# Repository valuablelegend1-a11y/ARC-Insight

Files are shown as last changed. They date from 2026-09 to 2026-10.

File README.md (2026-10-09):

# ARC-Insight 

## What it is:

ARC-Insight is a pair of AI glasses that directly connect to my homemade prompt transformer based AI: J.A.R.V.I.S. The frames carry the extensive payload of two bone conduction transducers for audio output, INMP441 and electret mics for audio input, a MAX30102 heart rate sensor for direct vitals tracking and emotion mapping, an OV2640 camera module for facial and object recognition, two 300mAh LiPo batteries for at least a full day of battery life at moderate usage, and to tie it all together; a custom ESP32-S3 based PCB!

The goal is a digital assistant that can come with me everywhere, while also expanding the abilities of Jarvis to do some things he couldn't from my desktop. He will be able to do things like answer personal questions, find search results, tell me what I'm holding or looking at, tell me who the person in front of me is, open up apps on my PC, start 3D prints, and even more. All while mapping my heartrate and speech patterns to respond with a genuine conversational feel through the GPT(NOT ChatGPT, they may have popularized the name GPT, but it just means a Generative Prompt Transformer, which is what Jarvis's speech is using).  

## How to use it:

First a quick primer, because this whole thing is two halves that have to work together, you have the glasses, which are the dumb half on purpose, they just record (microphone, camera, and your heart rate) and stream it all over Wi-Fi, and then you have Jarvis, which is the smart half, a desktop AI assistant I've been building for a while now, he's a custom language model with tools for things like object recognition, memory, web search, and much much more (I'm still deciding whether to ever make him open source, but if I do I'll drop a link here), and he does all the actual thinking and streams his reply back to the glasses so you hear it in your ears. Neither half is useful alone, you need both.

Setup happens in two places, and you only really do it once, the glasses and the PC.

The glasses half, the firmware lives in this repo at Code/firmware, you open it in PlatformIO (a coding tool for microcontrollers, sort of like a much more powerful Arduino IDE, it handles the build and the libraries for you), and before you build it the first time you need to put your Wi-Fi name and password, plus the address of the PC that runs Jarvis, into the little config file at Code/firmware/arcinsight_config.h (there are blanks right where they belong, you can't miss them), and then you plug the glasses in over USB, hit build and upload, and that's the only time you'll ever need a cable. After that the glasses just need power and to be on the same Wi-Fi as the PC, and they take care of themselves.

The PC half, you need Jarvis running (same desk assistant I mentioned, the glasses really are just a remote control for him), and you drop this arc_insight package into the same folder as the rest of his code, where it plugs in with a few lines and doesn't touch anything else (that was the whole design goal, he behaves exactly the same until the glasses show up), then you just start him up like normal, and when the glasses connect you'll see `ARCINSIGHT: glasses connected` in the console, and you're off.

Once they're connected it's all voice, you say "jarvis" (the same wake word you might already use at the desk, it becomes a habit fast) followed by whatever you need, like "what do you see", "who is this", "take a picture", or "how am I feeling", the last one is the heart rate sensor earning its keep, Jarvis reads your heartbeat, mixes it with the tone of what you said, and guesses if you're stressed or excited or just having a chill day, which is honestly the feature I'm most excited to see working. You can jump between the glasses and the desk whenever you want too, just say "jarvis, switch to glasses" or "jarvis, switch to laptop", or press Ctrl+Alt+G (the hotkey, it's easy to remap in the config), and Jarvis moves his ears, his mouth, and his eyes to wherever you are.

And when a newer firmware comes out, the cable stays in the drawer, you build the new image and run one little command, `python arc_insight\ota.py --bin ..\arc-insight\Code\.pio\build\arcinsight\firmware.bin`, and it streams the update over Wi-Fi on the same connection, the glasses verify it and reboot into the new version (if it fails the check they just stay on the old one, which is a nice safety net).

## Why I am building this:

- To learn real firmware development, power management, and how to package electronics into a wearable.
- To take Jarvis with me instead of keeping him chained to the desk.
- The heartbeat + speech sentiment combo lets Jarvis react to *how* I say things, not just *what* I say.

## Notes:

1. This is the first version of this project, so some things will change in future versions, like for instance the code may be optimized to run everything locally on the device, but that is not yet(look at note 3 for more information).
2. The code will not be all just written from memory for me for it all, I am still learning to code in general. That said, I really am diving deep into this, but it will still have some copy and paste from Google search, reddit snippets, or anything I need to make it work that I don't know.
3. Version 0 of this project is designed to be mostly a peripheral to my AI assistant J.A.R.V.I.S., who is a custom made Generative Prompt Transformer(GPT) based off of NanoGPT by Andrej Karpathy, with added tools for things like image and object recognition, memory, web search, and much much more. For more detail on that I will soon be making a repo to document that journey and how the AI runs now.
4. This is my first time designing a custom PCB, so forgive me if it is messy and not optimized, but I am quite proud of it and I think it will function how needed for this version.

## Assembly:


## Scehmatic:


## PCB:


## PCB Render:


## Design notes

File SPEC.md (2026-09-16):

# ARC-Insight Spec Sheet

## Architecture

The glasses are a 'wearable thin client'. The Jarvis brain stays on the desktop PC:

- Glasses (ESP32-S3 XIAO Sense): capture mic audio, on-demand camera frames, on-demand heart rate; play TTS audio via bone conduction.
- PC (Jarvis): STT (Google), the trained nanoGPT model, tools (weather, search, face rec via YOLO, memory, etc.), TTS (edge-tts). Streams synthesized audio back to the glasses.

The ESP32-S3 (512 KB SRAM) physically cannot run the Jarvis transformer, so no attempt is made to run a model on the frame.

## Hardware

- **Board:** Seeed Studio XIAO ESP32-S3 Sense (ESP32-S3R8, 240 MHz dual-core, 8 MB PSRAM, 8 MB flash)
- **Camera:** OV2640 / OV3660 on the Sense flex connector (2 MP), PSRAM-backed framebuffer
- **Mics:** onboard PDM mic (primary); external INMP441 I2S as fallback if placement is bad
- **Output:** 2x bone-conduction transducers behind the ears, driven by MAX98357A I2S amps
- **Sensors:** MAX30102 PPG heart-rate (I2C), power-gated
- **Power:** 2x ultra-slim 1S LiPo (300-400 mAh) in parallel -> XIAO BAT+ / BAT- pads, charged by onboard 100 mA charger via USB-C
- **Wake:** external electret + envelope comparator -> GPIO wake from deep sleep

## Power model

| State | Draw | Notes |
|---|---|---|
| Deep sleep (idle) | ~3 mA | Floor with Sense expansion attached; ~6-7 days on 2x300 mAh |
| Wake + streaming mic over Wi-Fi | ~55-110 mA | Mic-only ~54 mA, Wi-Fi active ~110 mA |
| Speaking (amp on) | +20-50 mA | Gate amp off otherwise |
| Camera capture | ~150-300 mA | Bursts only, <1 s per frame |
| Heart-rate burst | +1 mA | ~15-30 s samples on demand |
| Charge | 100 mA | Onboard charger, ~6 h to full |

Expected: ~1-2 days per charge with a couple hours of conversation per day.

## Emotion mapping (Jarvis tool)

Read heart rate in short bursts and combine with the sentiment of the latest utterance:

- High HR + negative words -> stressed
- High HR + positive/energetic words -> excited
- Low HR -> calm

Implemented later as a `read_mood` tool in the Jarvis `route_tool` pipeline.

3. On-device wake word (ESP-SR WakeNet) to stop constant streaming.
4. Camera capture -> JPEG -> PC YOLO (reuse existing vision tools).
5. Heart-rate sensor + DSP + logging.
6. Battery mgmt, carrier PCB, mechanical integration into the frame.

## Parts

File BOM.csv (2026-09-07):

Item | Quantity | Unit Price | Link | Notes
Custom PCB | 1 | 65.52 | no link | A custom designed PCB with an ESP32-S3 chip for processing.
OV2640 24-pin DVP camera module (75MM-120) | 1 | 8.19 | https://www.aliexpress.us/item/3256805763260734.html | 2MP, DVP 24-pin 0.5mm FPC.
Bone conduction transducer | 2 | 6.96 | https://www.aliexpress.us/item/3256808698640901.html | 8-16 ohm, electromagnetic GD-02 style compact drivers.
3.7V 300mAh Lipo Batterys | 2 | 3.99 | https://www.aliexpress.us/item/3256804324797087.html | Total of about 400mAh, should last a full day of use before charge.
GY-MAX30102 heart-rate breakout | 1 | 2.09 | https://www.aliexpress.us/item/3256810169517122.html | heart rate sensor for emotion mapping.
Electret mic | 1 | 2.36 | https://www.sameskydevices.com/product/audio/microphones/electret-condenser-microphones/cmc-4013-2-smt-tr | Always-on wake-on-sound, wakes ESP32 from deep sleep via GPIO. Only peripheral that stays powered in deep sleep.
5 pack INMP441 I2S mic (MH-ET LIVE) | 5 | 3.55 | https://www.aliexpress.us/item/3256809614473821.html | Primary speech mic I2S into S3.
Face Shield For Lenses | 1 | 6.99 | https://www.amazon.com/Saillong-Replacement-Compatible-Shields-Grinding/dp/B0D8L11X2C/ref=sr_1_5 | Transparent face shield to be cut to size for glasses lenses.
Signal Antenna | 1 | 7.02 | https://www.amazon.com/Adafruit-2-4GHz-Flexible-Antenna-Connector/dp/B01E43VXO0 | A 50Ω 100mm 4dBi Antenna, plugs into board's U.FL port.

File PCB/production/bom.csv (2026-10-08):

Comment | Designator | Footprint | Qty | LCSC Part #
ESP32-S3FN8R2 | U1 | QFN-56-1EP_7x7mm_P0.4mm_EP4x4mm | 1 | C2913196
MAX98357A | U2 | TQFN-16-1EP_3x3mm_P0.5mm_EP1.23x1.23mm | 1 | C910544
MAX98357A | U3 | TQFN-16-1EP_3x3mm_P0.5mm_EP1.23x1.23mm | 1 | C910544
TP4054 | U4 | SOT-23-5 | 1 | C382138
MCP6541 | U5 | SOT-23-5 | 1 | C80839
ME6211C33M5G-N | U6 | SOT-23-5 | 1 | C82942
USB_C_Receptacle | J1 | USB_C_Receptacle_GCT_USB4105-xx-A_16P_TopMnt_Horizontal | 1 | C3025063
FPC_24PIN | J6 | Hirose_FH12-24S-0.5SH_1x24-1MP_P0.50mm_Horizontal | 1 | C202112
U.FL-R-SMT-1(80) | J8 | U.FL_Hirose_U.FL-R-SMT-1_Vertical | 1 | C88374
40MHz | Y1 | Crystal_SMD_3215-2Pin_3.2x1.5mm | 1 | C47089401
2.4nH | L2 | L_0402_1005Metric | 1
12pF | C1 | C_0402_1005Metric | 1 | C1547
12pF | C2 | C_0402_1005Metric | 1 | C1547
100nF | C3 | C_0402_1005Metric | 1 | C1525
100nF | C4 | C_0402_1005Metric | 1 | C1525
100nF | C5 | C_0402_1005Metric | 1 | C1525
100nF | C6 | C_0402_1005Metric | 1 | C1525
1uF | C7 | C_0402_1005Metric | 1 | C52923
10uF | C8 | C_0603_1608Metric | 1 | C19702
10uF | C9 | C_0603_1608Metric | 1 | C19702
100nF | C10 | C_0402_1005Metric | 1 | C1525
1.5pF | C11 | C_0402_1005Metric | 1 | C1552
1.5pF | C12 | C_0402_1005Metric | 1 | C1552
1uF | C13 | C_0603_1608Metric | 1
10uF | C14 | C_0603_1608Metric | 1 | C19702
10k | R1 | R_0402_1005Metric | 1 | C25744
33R | R2 | R_0402_1005Metric | 1 | C25105
33R | R3 | R_0402_1005Metric | 1 | C25105
2.2k | R4 | R_0402_1005Metric | 1 | C25879
10k | R5 | R_0402_1005Metric | 1 | C25744
10k | R6 | R_0402_1005Metric | 1 | C25744
10k | R7 | R_0402_1005Metric | 1 | C25744
5.1k | R8 | R_0402_1005Metric | 1 | C105872
5.1k | R9 | R_0402_1005Metric | 1 | C105872

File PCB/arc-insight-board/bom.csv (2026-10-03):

Reference | Qty | Value | DNP | Exclude from BOM | Exclude from Board | Exclude from Simulation | Exclude from Position Files | Footprint | Datasheet
C1,C2 | 2 | 12pF |  |  |  |  | ${EXCLUDE_FROM_POS_FILES} | Capacitor_SMD:C_0402_1005Metric
C3,C4,C5,C6,C10 | 5 | 100nF |  |  |  |  | ${EXCLUDE_FROM_POS_FILES} | Capacitor_SMD:C_0402_1005Metric
C7 | 1 | 1µF |  |  |  |  | ${EXCLUDE_FROM_POS_FILES} | Capacitor_SMD:C_0402_1005Metric
C8,C9,C14 | 3 | 10µF |  |  |  |  | ${EXCLUDE_FROM_POS_FILES} | Capacitor_SMD:C_0603_1608Metric
C11,C12 | 2 | 1.5pF |  |  |  |  | ${EXCLUDE_FROM_POS_FILES} | Capacitor_SMD:C_0402_1005Metric
C13 | 1 | 1µF |  |  |  |  | ${EXCLUDE_FROM_POS_FILES} | Capacitor_SMD:C_0603_1608Metric
J1 | 1 | USB_C_Receptacle |  |  |  |  | ${EXCLUDE_FROM_POS_FILES} | Connector_USB:USB_C_Receptacle_GCT_USB4105-xx-A_16P_TopMnt_Horizontal | https://www.usb.org/sites/default/files/documents/usb_type-c.zip
J2 | 1 | Conn_01x06 |  |  |  |  | ${EXCLUDE_FROM_POS_FILES} | Resistor_SMD:R_Array_Convex_8x0602
J3 | 1 | Conn_01x05 |  |  |  |  | ${EXCLUDE_FROM_POS_FILES} | Resistor_SMD:R_Array_Convex_5x0603
J4,J5,J7 | 3 | Conn_01x02 |  |  |  |  | ${EXCLUDE_FROM_POS_FILES} | Connector_Wire:SolderWire-0.5sqmm_1x02_P4.6mm_D0.9mm_OD2.1mm
J6 | 1 | FPC_24PIN |  |  |  |  | ${EXCLUDE_FROM_POS_FILES} | Connector_FFC-FPC:Hirose_FH12-24S-0.5SH_1x24-1MP_P0.50mm_Horizontal
J8 | 1 | U.FL |  |  |  |  | ${EXCLUDE_FROM_POS_FILES} | Connector_Coaxial:U.FL_Hirose_U.FL-R-SMT-1_Vertical
L2 | 1 | 2.4nH |  |  |  |  | ${EXCLUDE_FROM_POS_FILES} | Inductor_SMD:L_0402_1005Metric
M1 | 1 | Electret |  |  |  |  | ${EXCLUDE_FROM_POS_FILES} | Sensor_Audio:CUI_CMC-4013-SMT
R1,R5,R6,R7 | 4 | 10kΩ |  |  |  |  | ${EXCLUDE_FROM_POS_FILES} | Resistor_SMD:R_0402_1005Metric
R2,R3 | 2 | 33Ω |  |  |  |  | ${EXCLUDE_FROM_POS_FILES} | Resistor_SMD:R_0402_1005Metric
R4 | 1 | 2.2kΩ |  |  |  |  | ${EXCLUDE_FROM_POS_FILES} | Resistor_SMD:R_0402_1005Metric
R8,R9 | 2 | 5.1k |  |  |  |  | ${EXCLUDE_FROM_POS_FILES} | Resistor_SMD:R_0402_1005Metric
U1 | 1 | ESP32-S3 |  |  |  |  | ${EXCLUDE_FROM_POS_FILES} | Package_DFN_QFN:QFN-56-1EP_7x7mm_P0.4mm_EP4x4mm | https://www.espressif.com/sites/default/files/documentation/esp32-s3_datasheet_en.pdf
U2,U3 | 2 | MAX98357A |  |  |  |  | ${EXCLUDE_FROM_POS_FILES} | Package_DFN_QFN:TQFN-16-1EP_3x3mm_P0.5mm_EP1.23x1.23mm | https://www.analog.com/media/en/technical-documentation/data-sheets/MAX98357A-MAX98357B.pdf
U4 | 1 | TP4054 |  |  |  |  | ${EXCLUDE_FROM_POS_FILES} | Package_TO_SOT_SMD:SOT-23-5
U5 | 1 | Comparator |  |  |  |  | ${EXCLUDE_FROM_POS_FILES} | Package_TO_SOT_SMD:SOT-23-5
U6 | 1 | ME6211C33M5 |  |  |  |  | ${EXCLUDE_FROM_POS_FILES} | Package_TO_SOT_SMD:SOT-23-5 | https://www.lcsc.com/datasheet/lcsc_datasheet_2304140030_MICRONE-Nanjing-Micro-One-Elec-ME6211C33R5G_C235316.pdf
Y1 | 1 | 40MHz |  |  |  |  | ${EXCLUDE_FROM_POS_FILES} | Crystal:Crystal_SMD_3215-2Pin_3.2x1.5mm

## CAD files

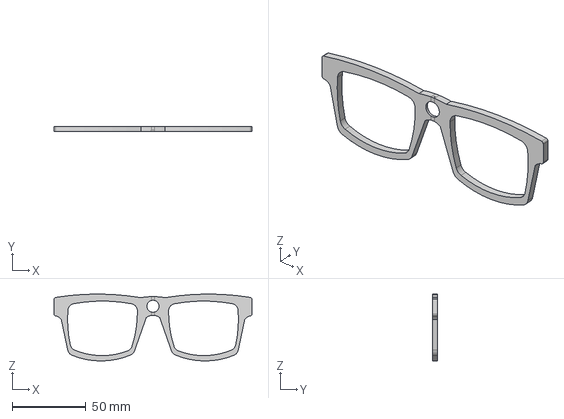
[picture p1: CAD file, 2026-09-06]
CAD/Step File Types/ARC-VisionFrames.step
134.6 x 3.69 x 45.5 mm

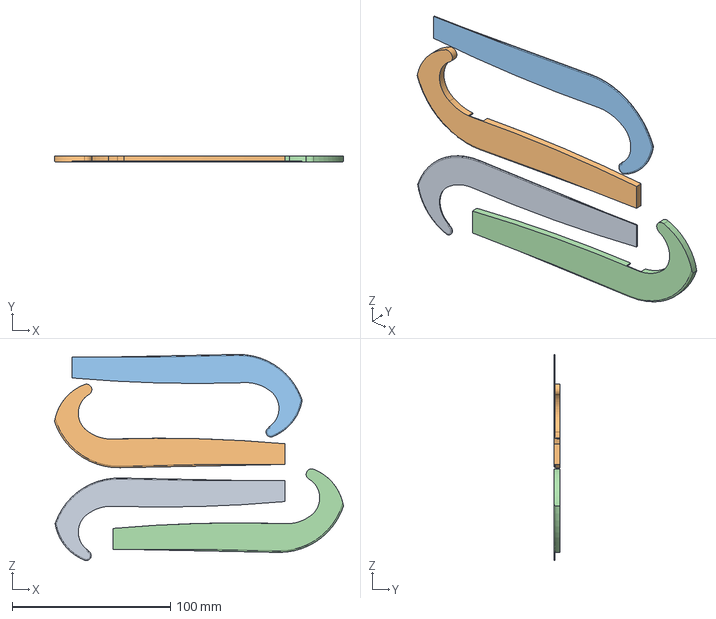
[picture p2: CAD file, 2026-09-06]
CAD/Step File Types/ARC-VisionArms.step
182.9 x 3.81 x 130.4 mm

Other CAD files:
CAD/Fusion File Types/ARC-VisionArms.f3z
CAD/Fusion File Types/ARC-VisionFrames.f3z

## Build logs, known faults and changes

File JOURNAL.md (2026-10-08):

---
Title: "ARC-Insight"
Author: "Jadon Persun"
Description: "AI glasses with a custom PCB"
Created At: 2026-08-07
---

# August 7: I made some basic drawings.
As usual for my projects I started off with some simple drawings of my idea, really the point of them is just to get a physical picture in my head before starting the true design process. Really the point of this whole build is to have a wearable device that I can use to communicate with my homebuilt, custom made transformer based AI: J.A.R.V.I.S. He also has tools and things to answer questions like weather, time, distances, facial recognition(through the camera), and more. For all of this, I decided to go with the Seeed Studio XIAO ESP32-S3 board, which is pretty small  and should work well. Then a couple other components that I know will be necessary, and I did a few renditions of the basic design to try to get a good style to fit what I was looking for, which I'm sure I will change more when I do the actual CAD of the project. For the most part these designs were simple, because the big benefit of small-scale projects is that there is literally just less area to manage. I also debated whether to go with some basic bluelight glasses lenses, or another simple option. Ultimately I decided that it would be slightly complex to try to model glasses frames around existing lenses, and really the point of these glasses is to be able to talk to J.A.R.V.I.S. when I'm AWAY from my computer, meaning bluelight would realistically not be needed.




**Time Spent: 1 Hour**

# August 10: I started designing.
So to start off the project I set up the repo, made a quick outline of how I want it to work, and made sure I knew what the requirements were. Then I started working on researching all the parts for the BOM, and I decided to use an ESP32-S3 mini version from seed studio for the main board(only 22mm tall) so I setup the rest of my components around that. I wanted the glasses to have good bone conduction transducers for audio, a heartbeat sensor for emotion analyzing, a camera for object and facial recognition, good mics for wake word detection and good input audio clarity, and plenty big batteries to make sure they would last the whole day. I also wanted the lenses to be a simple clear polycarbonate, as discussed in the previous entry, since trying to build the lenses frames around other lenses would be quite difficult. After getting a basic idea for each of the parts, I researched and made sure it would all work, then that it would all work together, and got it all nicely formatted in the BOM.csv file.




**Time Spent: 2 Hours**

# August 14: I started the CAD and pivoted my objective.
The next thing to work on was the CAD designs for the 3d printed frame(maybe later even made in metal by PCBWay!). The first thing I did before even starting my designs was to look up different glasses styles, I really wanted these to have the right look, and be stylish along with functional. It took me a couple tries of redoing the design completely, until I liked how the front frames came out. A pretty classic glasses look, but slightly redone to fit my face better and work correctly. Then there were the arms of the frame. These were much harder, because they needed to be big enough to fit all the components, and still look like glasses not a VR headset. Ultimately I realized that the board I had selected really would just not work for a low profile glasses frame. The size was too tall, the pins slightly too limited, and the usability did not fit my asparations. So I made a risky decision; I would design my first ever custom PCB. I got to work right away on researching how it all works, I have never done one before so there was a lot to learn. I decided on the ESP32-S3 chip still, because it had built in camera support and things like that that really fit what I needed. Before too long I had the basic framework of how to start, and I decided to start work on the schematic. This was a very time consuming process, since I didn't know anything about the software I was basically looking up every single baby step. Before too long I had figured out some keyboard shortcuts and had the basic idea down, then it came to the portion of the process where I just needed to carefully add all the parts correctly and get them all wired. After working on it almost every waking second of my day, I managed to finish the basic schematic with all the components I would need.




**Time Spent: 2.5 Hours**

# August 16: I continued work on the custom PCB.
So now that I got the schematic for the PCB all set up, it was time to start the actual component placement. At first I pretty much just threw everything in a rectangle in a way that they all fit together as tightly as possible with little bits of extra room. Then when I went to run the traces I realized I had not optimized it very well at all, out of my 200+ connections, *only 23 could be made.* So I went back to the drawing board, I tried rearranging the components in a much better layout for the traces, and I did need to largely increase the size of the pcb outline to make it all seem to work better. And since it took so long for the PCB traces the first time, I ended up downloading the app freerouting, which is an auto-router for PCB traces. It did pretty well and jumped the connections up to 118, which was obviously closer but still not great. So I took that partially traced board back to KiCAD and tried to route the remaining traces myself. I managed to get a few more, but there were still wayyy too many unconnected pads. I went through this cycle another time or two, redesign, auto-route, manually route, fail. After it failing so many times I decided to try a different method, I realized that the most traces that were being left unconnected were 1. Ground and 2. The camera FPC connector to the esp32 chip. That made me realized that there must be a better way to connect all the ground pads, and that's when I learned what a ground pour was. I got that all setup and checked the connections, it managed to fix **31** connection issues. That was a huge help and a great motivation booster, that led me to keep trying orientation options for the remaining disconnections. I decided to try to position the esp32 chip directly next to the FPC connector for easy trace running, but really it just made the whole board as thick as the board I previously rejected. So I ditched that idea, and that's when I realized that if I slightly edited my original component placement in the glasses frames, I could make the PCB be by itself in one arm, leaving me almost 70mm of length to work with, as opposed to the 40 or so I had tried to cram in before. That was a game changer, and I was able to give each component much more room and also a cleaner setup in general. I reran the auto-tracing, and only 8 were disconnected! Those few were plenty simple to just route using a via or two that the automated program couldn't. 



**Time Spent: 5 Hours**

# August 20: I updated the CAD with the new parameters.
Now with me deciding to go the custom PCB route I had a lot more flexibility in the glasses frames. So I worked through a couple options for the arms, and initially I was just going to have the whole arm be about 16mm thick to fit the PCB. But after looking at it and comparing I decided to go with a curved bottom and slightly slanted top, which would allow the PCB plenty of room and still keep the arms relatively thin. At first the arms ended up being still almost 20mm wide, which was the exact thing I was trying to avoid by creating the custom PCB. So I messed with the PCB a bit to shrink it down a bit, and was able to get the arms down to 19mm at the smallest point, which still was not ideal. Then I took a step away from it for a bit, and when I went back I realized that somehow I had completely misread the PCB specs thinking it was 17mm, when it was actually *13.75mm* that meant I could shrink the arms width down exponentially, getting the largest part of the arm down to about 16mm. This made the whole look a lot cleaner and really made the whole design work better too.




**Time Spent: 3 Hours**

# August 21: I tested some new printing techniques.
So I wanted to get a good idea of how to print each piece, so I threw some in the slicer to do a quick print. For the lenses frames I started out by putting them face down on the plate for printing ease. I went through a couple testing models with the arms attached differently to try to get a good idea of how to secure them for maximum stability and clamping force for the sensor and transducers. Most of these test were also done in between the versioning of the arms, as discussed in the previous journal entry, meaning most of these test were done with the thicker arms. After a couple tests, I determined that the best way to have the body of the arms open to insert the components was to make one side with the extruded walls, and the other as a flat piece on the outside for looks. Then I checked out a couple versions with an ironed top, which really gave them a clean look. I also ended up deciding to go with a carbon-fiber PETG for the frames, as this would give a great strength to weight ratio, plus the carbon fiber added really helps remove layer lines for that nice clean 'machined' look. Ultimately I did need to do some slight mods to the lenses frames to make them look better with the arms, and to add the camera hole and remove the curve to get that nice ironed look.
Then I also added whatever the parts are called on the frames that rest against the sides of your nose, actually let me look up what those are called quick, hold on...Okay I'm back, apparently they are just called 'nose pads' which is wayyy too generic of a name in my opinion, a part like those is exactly the kind of thing that should have some ridiculous name that makes no sense and has no origin. Anyways I designed those as separate pieces to glue on, because if they were attached then I wouldn't be able to print the glasses flat down meaning they couldnt be ironed and look nicer.






**Time Spent: 2 Hours**

# August 25: I exported the PCB and configured it in JLCPCB.
So now that the PCB was designed, I went ahead and exported it to add to JLCPCB to see how it all imported. It wasn't too hard to learn how to export the gerbers, BOM, and CPL files but it did take a little bit of research to make sure I got everything right. After that I just uploaded them all into jlc to check requirements and pricing. This is when I realized that they would not be able to add the electret mic, so I would need to hand-solder that. So I removed it from my PCB BOM and found a suitable replacement on SameSky. The total ended up being MUCH more than I anticipated, which really meant I had to get the board perfect the first time, so I didn't need to spend hundreds of dollars on iterations. Thankfully I do have some first timer coupons so that will help with the cost, but it was still steep enough that I decided to also upload it to PCBWay to see if their prices were any better, but it ended up being probably a bit more. However, after I put the board in my cart within a few hours I got an email from them explaining how there were a few errors with my design. This was super helpful as a first time PCB designer I really didn't know some things(I had put some vias in the SMD pads which apparently is a no-no). So I spent a little bit moving all of those to make sure there would be no shorts, then I just ran DRC and fixed all the errors. And while doing that switch around, I happened to notice that I had accidentally used the wrong footprints for the MAX98357A, so the chips would not actually fit on the pads when JLC went to assemble it. That just meant replacing the footprint in the schematic, and then rewiring it. It wasn't too complicated of a process and that part was done pretty quickly. Then came the PCB. Unfortunately the updated footprints were much larger than their predecessors, meaning there would need to be a lot of reworking to get them to fit. I had to move R3, R1, and R5 around a little bit to make sure the pieces would fit, and I managed to get them squeezed in there eventually. Unfortunately that left almost no room for the traces, and it took FOREVER to route them all, and try to get them to connect correctly, and add more vias to get everything to work. Eventually I got all the pads connected, arguably with way too many vias but who's keeping track? Then I ran DRC, and found about 30+ errors to fix. Most of them were simple tolerance issues, meaning I just had to slide a trace over or shift a via. After a little bit of work I got them all sorted out, and I went to edit the BOM to ensure everything was up to date. That's when I realized that I had completely forgotten to add an antenna connector. This also was not too complicated, and before too long I had researched and found the right part, and then I just threw it in the schematic, rearranged some traces and components, and had it all set up.





**Time Spent: 4 Hours**

# August 30: I fixed the VCC-GND short.
Today was the day to finally fix the VCC net that I discussed in the previous journal entry, basically all the VCC pads were connected to ground. This was a huge undertaking, and it started back in the schematic. Turns out, while I was setting up power flags, I had accidentally connected ground and VCC to the same one, I thought they were both the same type connecting so it didn't matter, but I was wrong. Obviously this part was a simple fix that went great and I had no problems with, but it caused more than a few issues in the PCB. However, before I went to that I did make sure to do a couple once-overs of the schematic and make sure it looked fine, and ran ERC again to confirm there were no obvious issues(somehow I missed that last time). Then I realized that I hadn't actually added a step down convertor for the power, so I also had to throw in one of those to make sure there were no issues with that. It wasn't too hard, just adding it in and relabeling a few things, and since I already needed to reroute like 50 traces or something it wasn't a big deal to add 2 or 3 more. So then came the part that was not necessarily hard, but most certainly time consuming. The first part of rerouting I did was just to disconnect all the VCC pads from ground, which didn't take too long since I disconnected those wires in the schematic, so DRC just showed all the shorts. Then I started my run of reconnecting all those disconnected pads to the VCC net(and some to the new VBAT net which was just the power without the step down converter. When I say this took a long time, I mean I pretty much spent 6 hours across a weekend trying to get all these traces rerouted. Which was a lot harder to do with the updated VCC and VBAT nets, since when I had accidentally done them with ground they basically just made one HUGE net that was easy to connect to since it was everywhere. But honestly running traces and doing the PCB side of designing a PCB is one of my new favorite things to do, getting to manually work things around, find paths, move things, constantly refactor, and all of that is so rewarding, even if it can be upsetting at times. Really the only big actual issues I had were running the VBAT traces to the freshly updated MAX98357A modules, which were pretty tight in the new version, and the right one was extremely close to the border. I ended up needing to move the left one up and to the left a bit, then move the right one over to the left some, in order for me to be able to run the VBAT traces to each of the required pads. Then I did also need to completely reroute the traces from J4 up top, which was mostly just trial and error of finding the right path for a while. I finally got them both reconnected, then went back to the VCC and VBAT running. There were a multiple times where I had to slide like 4 traces in the same direction in order to run a new one through, which definitely did leave some traces slightly twisted around, but ultimately I realized the point of this PCB is to 1. Learn everything I am learning, and 2. Have a WORKING PCB, not necessarily a pretty one. After I got all the traces ran, I tested DRC, which gave me no less than 31 errors. Most of them were just clearance violations(probably due to the trace shoving mentioned a second ago) and were pretty easy to just scootch around until they fit correctly. There were also a couple that were issues with GND being isolated, so I did need to do some more trace running to fix all of those. Ultimately I got it all fixed, and you can be sure I will never be connecting VCC and ground again, even by accident.





**Time Spent: 6 Hours**

# September 2: I reexported everything.
Now that all the errors seemed to be fixed, I did ANOTHER thrice-over(surely that's a thing) then I did a quick glance in the 3d viewer to view my masterpiece. Then I simply exported all the files for the umpteenth time, then uploaded them to JLC, to get an idea of what it would all cost and how it would function. And after I added the gerbers, I saw an option that I had never even thought of, but maybe would be the most epic part of the whole PCB creation: Making the PCB black. Now that may sound a little simple, but I am a sucker for extremely sleek designs, and the thought of a black PCB just made me genuinely very excited. I made it all the way through the process, and the view of the main PCB is pretty great, it has a nice black design with gray traces that really do have a clean look. I also confirmed that shipping would be reasonable, and ensured that all the files were uploaded correctly, before saving it to my cart for later purchase. 




**Time Spent: 1 Hour**

# September 5: I added a 'button' of sorts.
Another thing that I wanted to add to the glasses was some sort of button to turn them on and off. So I decided to go the route of capacitive touch for it to make it super simple and clean. It really wasn't complicated, I just added the correct footprint and everything to the PCB, ran the trace, and then I will just solder the wire directly into it. Then I just reexported the gerbers and CPL and BOM files again, where I realized there was an issue with the origin of the files, causing the parts to be misaligned from where they were supposed to be. So I went through the process of just fixing those issues to ensure it would all be lied out correctly. After that I just updated them in the repo as well, and called it a day.




**Time Spent: 1.5 hours**

# September 6: I Started work on the code.
Now that all the physical parts were done, I needed to get working on the background: the code. This was going to be a HUGE process, and really my main goal is to get the functionality I want without having to redo any of J.A.R.V.I.S.s files, since ideally I would be able to literally walk up to my desk and pull off the glasses and instantly be using Jarvis on my desktop. There was a whole lot to do, so to be honest I started off by just doing a fresh run through of my Jarvis code, since I havent had too much time to edit it recently or even to use Jarvis. This allowed me to get a much better picture of how to build everything, and I started with the implementation. To start it off I created the arc_insight folder in the main J.A.R.V.I.S. folder, and started writing files. The first was bridge.py, this is there to install the hooks and the input gateway, really making sure it all works together and everything, but I couldn't do too much in there without some of the other files created. So I made my channels.py file, this one mainly functions as the IOManager, working with the channels, the utterance queue, and handling the heart rate and frame states. I created it by writing down everything Jarvis and the glasses both needed to share and turning that into the spine of one class: the current channel, the queue of recognized utterances, the latest camera frame, and the latest heart rate, each with a timestamp so nothing ever acts on stale data. The wake-word check fell out of that pretty naturally as a clean seam, so transcripts come in, get stripped of the "jarvis" keyword when it's required, and get dropped into the queue for the main loop to pick up; the heart rate also feeds straight into the emotion engine, which is why I threaded that in from the start. Then I made the server.py file, this one is meant to act as the websocket host for the glasses, it handles the audio input, the voice output, the camera, the heartrate, and all that data being sent back and forth. I built it in the simple progression of locking down the wire format first, a tiny protocol.py that just slaps one opcode byte onto every payload (PCM in, JPEG in, MP3 out, firmware chunks) then a bare websockets server with a dispatcher loop, then the fun part of hanging the voice pipeline onto it, a streaming STT that keeps a running noise floor and a speech gate so background silence never gets transcribed, and finally plumbing the camera, the heart rate events, and the TTS reply back down the same socket, plus a frame loop that politely asks the glasses for a photo on a timer. Those were my starting point, but stepping back from it knowing what I needed to work on gave me a much clearer mental blueprint of how it needed to function, which let me think about how I wanted to build it in much more detail.





**Time Spent: 3 hours**

# September 9: I kept working on the code.
The next files I created were ota.py and stt.py. The file ota.py is the firmware OTA uploader, it works by connecting to the server as its own client, chopping the firmware file into 4KB chunks and shoving them through the websocket down to the glasses, which flashes each one into the OTA partition and acks back so it knows everything made it, then the glasses verify, switch over, and reboot and ota.py waits until it sees that restart. Simple stuff, I built it by just using the same websockets library as the server and reading the wire format out of protocol.py, so it's really just "send a chunk, wait for the okay, send the next." Then for stt.py, this one is for streaming VAD and Google STT on glasses audio, which works by keeping a running noise floor of the background sound, letting anything a few times louder than that trip a speech gate, then buffering the whole utterance until it goes quiet long enough and shipping the raw audio off to Google's recognizer, which spits back the text, then the wake word gets stripped off. Pretty simple to build by just using recognize_google directly on the raw audio bytes, no files involved, the only real work was the noise floor part. Then after I created those files I just threw together vision.py, which handles the YOLO object detection and facial recognition, which weren't too hard since I'd already done some of them for the main Jarvis program. Really my understanding of how the program works is it takes the picture, converts the pixels into matrix numbers, then streams them to the PC, which then decodes that matrix of numbers to turn it back into an image. Honestly that's about as deep as it goes, but I am honestly considering looking into 'taking' some basic free online classes in linear algebra to get a better idea of how the encoding and everything works.





**Time Spent: 2 Hours**

# September 10: I finished out the rest of the glasses python code.
The remaining files were more of the same, config.py is just every knob in one place with defaults and a config.json to override bits, and glasses_tools.py is the box of tools I hang on Jarvis for glasses mode, like "what do you see" and "who is this" and "how am I feeling," each with a guard so he won't use the camera or heartbeat when the glasses aren't connected. But the best part, and honestly the coolest part of the whole glasses, was the emotion engine, and that one got me genuinely excited because the laptop can't do it. My desktop Jarvis has no idea how I'm feeling beyond what I say, but the glasses have a heartbeat sensor pressed against my skin, giving it a window into my nervous system none of my builds ever had. So the sentiment side has a hand-written lexicon of words ranked positive to negative, with negations and intensifiers, squished into one compound score. The heart side cleans the raw pulses and figures out my rate, how far it is above resting, words, and heartbeat, then ages them so old feelings fade. It also uses the fusion and engine files to handle that, and votes between calm, neutral, stressed, excited and sad, only committing after it holds a while so it doesn't flip-flop. And it tracks what signals pushed it there so Jarvis can say things like "you seem stressed; signals: raised heart rate, negative wording." That was the last of the real files, and with that, the code side was done.






**Time Spent: 3.5 hours**

# September 12: I started the firmware.
The first files I made for the firmware were the boring ones that everything else leans on. There is a single pins.h that puts every pin in one place. The microphone, the amp, the camera, the heartbeat sensor, the touch pad, all of them. That alone saved me from a lot of confusion later. Then arcinsight_config.h with all the constants like the computer address, the sample rate and the timeouts. Then settings, which saves the wireless and host info to flash with the Preferences library. So I never have to hardcode my home network into the firmware. The protocol.h file is just the list of message types that I decided on, just one byte per message. And main.cpp just wires everything together, sets up the parts and runs the loop. All of this was me writing down every decision in one obvious place. That was the framework. Pretty basic and unfun, but it made the rest way easier.






**Time Spent: 1.5 hours**

# September 13: I kept working on the firmware
The audio side came next, and honestly it was the scariest part for me. The mic and the audio amp share one I2S bus with a 32 bit wire format, and that wire rate is too fast for speech software to like. So the audio_io files are where all of that lives. That is the mic input, the amp output and the frame timing all together. Then I built the resampler that moves everything down to 16k and chops it into clean 20 millisecond frames. Those frames are what get sent to the computer for speech. Getting the resampler right took some fiddling, because I had to match the timing exactly or the audio would drift. The playback direction was its own problem. Jarvis replies with MP3, and the ESP32 does not decode that on its own. I fumbled around with a couple of decoders and settled on libhelix. I wrapped it in my own mp3_decode file so it takes MP3 bytes in and gives good PCM out to the amp. That wrapper was the last piece of the puzzle. Audio in and audio out were both setup, and that got me pretty excited for testing, because I am starting to see how it will all come together and work for a seamless experience.




**Time Spent: 2.5 Hours**

# September 14: I made the firmware link to the PC.
With the audio working, I needed the glasses to actually reach the computer. The link files start the wireless connection and then a websocket client that talks to the server on my PC. I used the WebSockets library for the ESP32 instead of writing my own socket code, and that saved me a lot of pain. It sends the mic frames and the pictures, and it listens for incoming commands and audio. The framing was easy, since I already had the protocol header done. The trickier part was that connecting can block the whole board for a second or two, so I had to make sure that never happened in the middle of audio streaming. The camera files were simpler than I feared. The ESP32 has built in camera support, so capture is basically one ask for a JPEG. I made it lazy, so it only powers up when something actually wants a photo. That keeps the power draw down. The main gotcha there was the driver version, and I just had to make sure the wiring matched what the driver expects. The heart files were the hardest of this bunch. The sensor reads an optical pulse against my skin and returns a bpm with a confidence value. It took me a while to figure out the settings, and I ended up ignoring the weak readings and only sending the good ones up. The nice part is that the heart rate gets posted as an event, so the computer gets a little beat update instead of a full stream. Between the link, the camera and the heart sensor, the glasses were finally a full input device. I still cannot test any of it in actual glasses yet, but the devkit tells me the plumbing is right.





**Time Spent: 3 hours**

# September 15: I finished the firmware.
The last files were about power and behavior, and this is where the glasses became something wearable. The sleep files handle, well, sleep. It wakes on a voice comparator on its own pin, so only real sound can wake it, plus a timer guard that forces a wakeup after a long stretch of nothing. I chose that wake method on purpose. Anything that needs a button press can get woken up in a pocket. The touch files turn the touch pad into a button. A tap goes back to listening, a double tap saves a picture, and holding it for five seconds sleeps. Getting the gesture timing right took a few tries. The wake word files were the cool ones. The glasses listen for the word "jarvis" right on the device while the radio is off. I did not want any big model file, so I built a simple spotter from scratch. It makes acoustic features with an FFT, stores a template of the word, and matches it with a similarity score. You teach it three times over serial and it remembers. That one took the most head scratching, because I was building the whole thing by hand. Finally I made a selftest build that exercises every pin on the bench. If a part is not soldered right, it tells me in seconds. With power and behavior done, the firmware was basically complete, and the next steps will be on physical hardware.




**Time Spent: 2 Hours**

# September 15: I did a once over of the repo and submitted.
Now that all my designing was complete I started doing a once over of everything to make sure it was ready for submission. That's when I realized I hadn't actually added an assembly image to the readme, so I reopened Fusion, snapped the picture, and slid it cleanly in. That also brought up the other little reminder that I had not yet updated the schematic to use labels instead of wires. For context, when I was first learning it I just used wires because that's what I thought the best option was, then I posted an image on slack asking for tips, when someone said I should really be using labels for it all. So that's what I did, really it wasn't difficult, it just took FOREVER because there were so many connections to redo(or at least it felt like forever because it was pretty dull work, I much prefer PCB to schematic fixes, all in all it was probably just an hour for that). After I got all that sorted out I threw an image of that in the readme as well, and then just double checked the full readme to ensure it was all set. After I was confident that was set up fine, I made a couple quick pricing updates to the BOM, and some quick changes to the spec file. Then the ARC-Insight 0 was designed and ready for submission and building!



**Time Spent: 1.5 Hours**

# October 2: I updated the schematic.
After the project got returned for some edits needed on the schematic, I got right to work fixing it all up. It only took a bit, because there were mostly some simple edits to do. The first thing was just to add some wires for the net labels, to make sure it was more readable and looked right. That wasn't hard just a little time consuming for all the connections. Then I added the pulldowns on my USBC CC pins as suggested, and got the ground wired to USBC shield. Then I simply removed L1 and cleaned that up so there were no issues with VCC. After that I updated the PCB from the schematic, fixed all the needed connections, then I ran DRC and worked through the errors. they were super simple, just two tolerance issues that I quickly fixed, and one naming problem that I just had to redo in the schematic and update the PCB from. After that I added all the fixed files to github, retook screenshots for the README, and got it ready for resubmission.




**Time Spent: 2 Hours**

# October 7: I did more schematic edits.
So turns out I didn't completely understand the first reviewer when they asked me to do some edits, so it got returned again. Now thankfully I have a much clearer template of what I need to fix, so I could get right on the fixes. Most of the schematic work was simple, just moving things around, little bit of wiring, and some slight renaming for simplicity. There were a couple times where I had to redo the positioning of one component, and that in turn messed with another one, which just made the clutter worse. Thankfully it was all fixable and didn't take too much extra time. After the schematic was done I ran ERC and found zero errors, so then it was on to the PCB. Obviously the first thing I did was update from schematic, then I ran DRC to see what I was working with. I was mortified to find that there were *59 errors*. That really just absolutely shocked me and I had no idea where even to start. But I slowly started to work through them, and that's when I realized that some of the errors were because the two pads of a resistor or a capacitor were reversed. That led me to discover that I had accidentally flipped a couple components around in the schematic, changing what pins each of the wires or labels were connected to, and since the schematic doesn't show pin numbers for resistors and caps I had no idea. Thankfully this meant that literally all of the errors were due to this issue, and Y1 itself somehow was managing to cause 38 of the errors just by being reversed. So I flipped all the components the right way, reran DRC, and was pleased to find 0 errors. While I was already editing the PCB I did decide to add a silkscreen on the bottom just of the project PCB name, and myself as the designer. Then I got all the correct files added to the repo, exported the gerbers, cpl, and bom files and I was ready for another submission.




**Time Spent: 3 Hours**

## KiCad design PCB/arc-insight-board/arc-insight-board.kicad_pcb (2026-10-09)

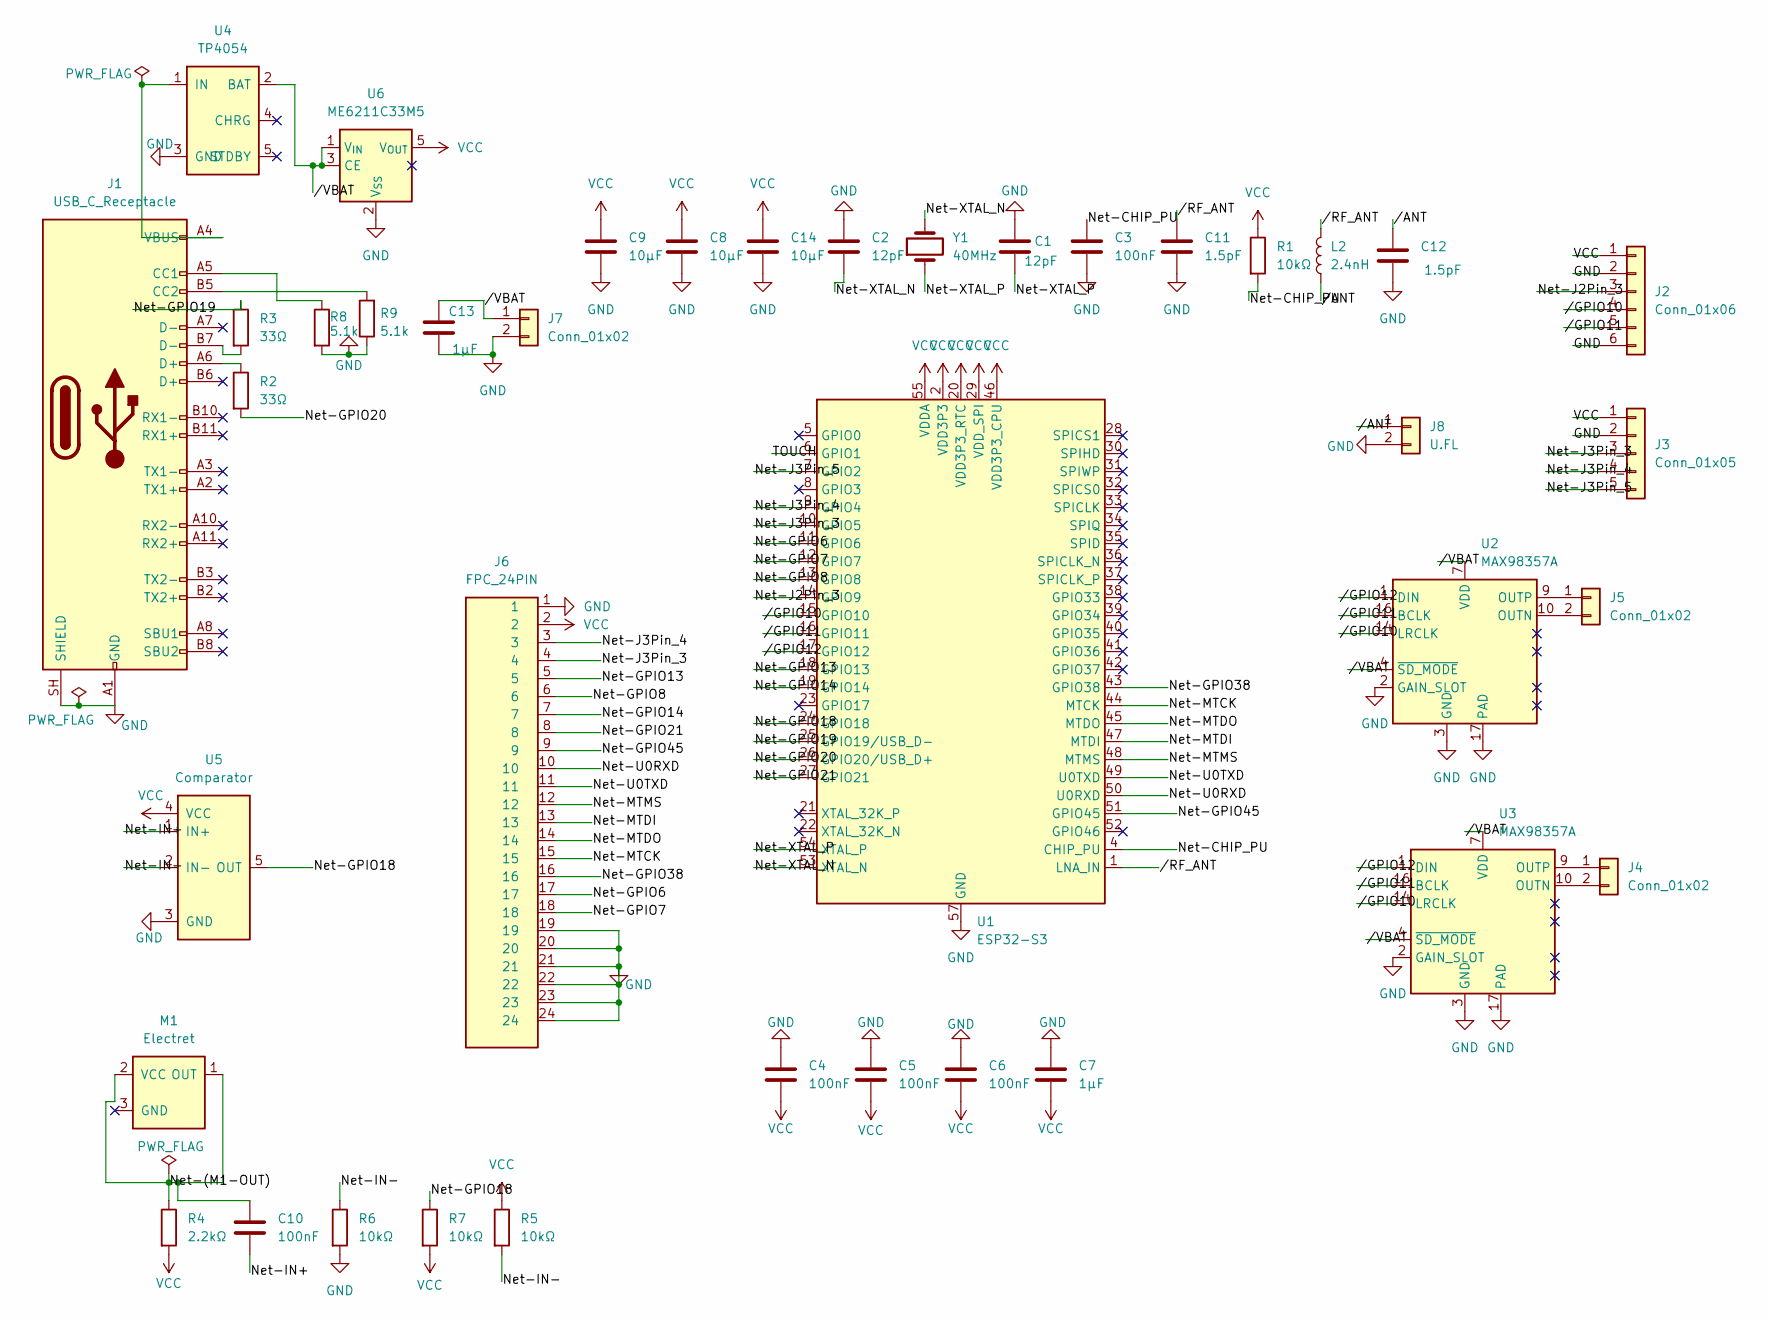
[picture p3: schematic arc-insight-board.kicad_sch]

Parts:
C1, C2: 12pF; C_0402_1005Metric
C3, C4, C5, C6, C10: 100nF; C_0402_1005Metric
C7: 1µF; C_0402_1005Metric
C8, C9, C14: 10µF; C_0603_1608Metric
C11, C12: 1.5pF; C_0402_1005Metric
C13: 1µF; C_0603_1608Metric
J1: USB_C_Receptacle; USB_C_Receptacle_GCT_USB4105-xx-A_16P_TopMnt_Horizontal
J2: Conn_01x06; R_Array_Convex_8x0602
J3: Conn_01x05; R_Array_Convex_5x0603
J4, J5, J7: Conn_01x02; SolderWire-0.5sqmm_1x02_P4.6mm_D0.9mm_OD2.1mm
J6: FPC_24PIN; Hirose_FH12-24S-0.5SH_1x24-1MP_P0.50mm_Horizontal
J8: U.FL; U.FL_Hirose_U.FL-R-SMT-1_Vertical
L2: 2.4nH; L_0402_1005Metric
M1: Electret; CUI_CMC-4013-SMT
R1, R5, R6, R7: 10kΩ; R_0402_1005Metric
R2, R3: 33Ω; R_0402_1005Metric
R4: 2.2kΩ; R_0402_1005Metric
R8, R9: 5.1k; R_0402_1005Metric
U1: ESP32-S3; QFN-56-1EP_7x7mm_P0.4mm_EP4x4mm
U2, U3: MAX98357A; TQFN-16-1EP_3x3mm_P0.5mm_EP1.23x1.23mm
U4: TP4054; SOT-23-5
U5: Comparator; SOT-23-5
U6: ME6211C33M5; SOT-23-5
Y1: 40MHz; Crystal_SMD_3215-2Pin_3.2x1.5mm

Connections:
/Net-(M1-OUT): C10.1, M1.1 (OUT), M1.2 (VCC), R4.1
/Net-CHIP_PU: C3.1, R1.2, U1.4 (CHIP_PU)
/Net-GPIO6: J6.17, U1.11 (GPIO6)
/Net-GPIO7: J6.18, U1.12 (GPIO7)
/Net-GPIO8: J6.6, U1.13 (GPIO8)
/Net-GPIO13: J6.5, U1.18 (GPIO13)
/Net-GPIO14: J6.7, U1.19 (GPIO14)
/Net-GPIO18: R7.1, U1.24 (GPIO18), U5.5 (OUT)
/Net-GPIO19: R3.1, U1.25 (GPIO19/USB_D-)
/Net-GPIO20: R2.2, U1.26 (GPIO20/USB_D+)
/Net-GPIO21: J6.8, U1.27 (GPIO21)
/Net-GPIO38: J6.16, U1.43 (GPIO38)
/Net-GPIO45: J6.9, U1.51 (GPIO45)
/Net-IN+: C10.2, U5.1 (IN+)
/Net-IN-: R5.2, R6.1, U5.2 (IN-)
/Net-J2Pin_3: J2.3, U1.14 (GPIO9)
/Net-J3Pin_3: J3.3, J6.4, U1.10 (GPIO5)
/Net-J3Pin_4: J3.4, J6.3, U1.9 (GPIO4)
/Net-J3Pin_5: J3.5, U1.7 (GPIO2)
/Net-MTCK: J6.15, U1.44 (MTCK)
/Net-MTDI: J6.13, U1.47 (MTDI)
/Net-MTDO: J6.14, U1.45 (MTDO)
/Net-MTMS: J6.12, U1.48 (MTMS)
/Net-U0RXD: J6.10, U1.50 (U0RXD)
/Net-U0TXD: J6.11, U1.49 (U0TXD)
/Net-XTAL_N: C2.2, U1.53 (XTAL_N), Y1.2
/Net-XTAL_P: C1.1, U1.54 (XTAL_P), Y1.1
/TOUCH: U1.6 (GPIO1); also elsewhere on the board
//ANT: C12.1, J8.1, L2.1
//GPIO10: J2.4, U1.15 (GPIO10), U2.14 (LRCLK), U3.14 (LRCLK)
//GPIO11: J2.5, U1.16 (GPIO11), U2.16 (BCLK), U3.16 (BCLK)
//GPIO12: U1.17 (GPIO12), U2.1 (DIN), U3.1 (DIN)
//RF_ANT: C11.1, L2.2, U1.1 (LNA_IN)
//VBAT: C13.1, J7.1, U2.4 (~SD_MODE), U2.7 (VDD), U2.8 (VDD), U3.4 (~SD_MODE), U3.7 (VDD), U3.8 (VDD), U4.2 (BAT), U6.1 (V_{IN}), U6.3 (CE)
GND: C1.2, C2.1, C3.2, C4.1, C5.1, C6.1, C7.1, C8.2, C9.2, C11.2, C12.2, C13.2, C14.2, J1.A1 (GND), J1.A12 (GND), J1.B1 (GND), J1.B12 (GND), J1.SH (SHIELD), J2.2, J2.6, J3.2, J6.1, J6.19, J6.20, J6.21, J6.22, J6.23, J6.24, J7.2, J8.2, R6.2, R8.2, R9.1, U1.57 (GND), U2.2 (GAIN_SLOT), U2.3 (GND), U2.11 (GND), U2.15 (GND), U2.17 (PAD), U3.2 (GAIN_SLOT), U3.3 (GND), U3.11 (GND), U3.15 (GND), U3.17 (PAD), U4.3 (GND), U5.3 (GND), U6.2 (V_{SS})
unnamed: J1.A5 (CC1), R8.1
unnamed: J1.B5 (CC2), R9.2
unnamed: J1.A6 (D+), R2.1
unnamed: J1.B7 (D-), R3.2
unnamed: J4.1, U3.9 (OUTP)
unnamed: J4.2, U3.10 (OUTN)
unnamed: J5.1, U2.9 (OUTP)
unnamed: J5.2, U2.10 (OUTN)
unnamed: J1.A4 (VBUS), J1.A9 (VBUS), J1.B4 (VBUS), J1.B9 (VBUS), U4.1 (IN)
VCC: C4.2, C5.2, C6.2, C7.2, C8.1, C9.1, C14.1, J2.1, J3.1, J6.2, R1.1, R4.2, R5.1, R7.2, U1.2 (VDD3P3), U1.3 (VDD3P3), U1.20 (VDD3P3_RTC), U1.29 (VDD_SPI), U1.46 (VDD3P3_CPU), U1.55 (VDDA), U1.56 (VDDA), U5.4 (VCC), U6.5 (V_{OUT})

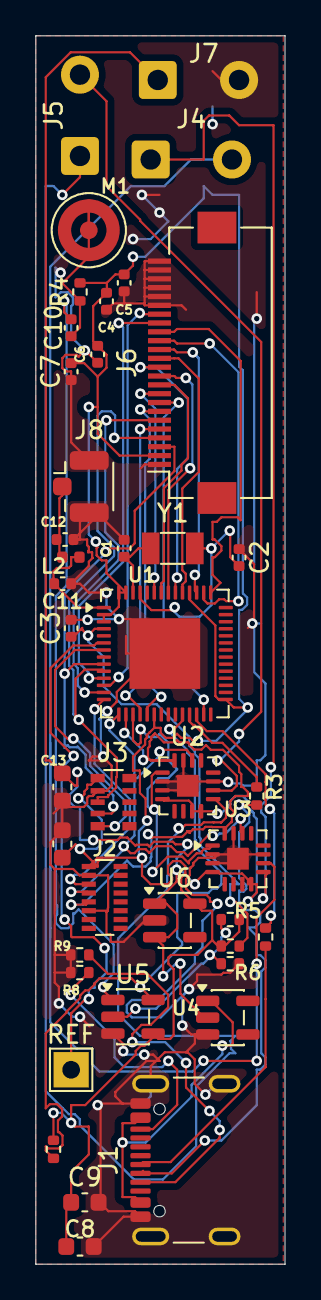
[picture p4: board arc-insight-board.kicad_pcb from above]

Board: 2 copper layers, 14.1 x 69.5 mm, 41 parts (0 on the bottom side), 45 nets.

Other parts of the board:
REF: TestPoint_THTPad_2.0x2.0mm_Drill1.0mm

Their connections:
/TOUCH: REF.1; also elsewhere on the board

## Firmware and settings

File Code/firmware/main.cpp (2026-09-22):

#include <Arduino.h>
#include <WiFi.h>
#include <esp_ota_ops.h>
#include <esp_partition.h>

#include <stdio.h>
#include <string.h>

#include "ancs.h"
#include "arcinsight_config.h"
#include "audio_io.h"
#include "camera.h"
#include "heart.h"
#include "kws.h"
#include "link.h"
#include "pins.h"
#include "protocol.h"
#include "selftest.h"
#include "settings.h"
#include "sleep.h"
#include "touch.h"

using namespace arcv;

namespace {

Link gLink;
AudioIO gAudio;
Heart gHeart;
Camera gCamera;
Touch gTouch;
Kws gKws;
#if ARCI_ANCS_ENABLE
Ancs gAncs;
Ancs::Msg gLastAncsMsg;
bool gAncsMsgPending = false;
#endif

enum class DevState { Listen, Active };
DevState gState = DevState::Listen;
bool gStreaming = false;
bool gSnapshotPending = false;
uint32_t gLastCmdMs = 0;
uint32_t gStateSinceMs = 0;
uint32_t gOtaRecv = 0;
uint32_t gOtaSize = 0;
bool gOtaActive = false;
esp_ota_handle_t gOtaHandle = 0;
const esp_partition_t* gOtaPartition = nullptr;

void finalizeOta() {
  esp_err_t err = esp_ota_end(gOtaHandle);
  gOtaActive = false;
  if (err != ESP_OK) {
    gLink.sendText("{\"type\":\"ota_event\",\"event\":\"device_error\","
                   "\"detail\":\"verify failed (%d)\"}",
                   (int)err);
    return;
  }
  gLink.sendText("{\"type\":\"ota_event\",\"event\":\"ota_done\"}");
  esp_ota_set_boot_partition(gOtaPartition);
  esp_restart();
}

bool linkConnection() {
  return gLink.connect(settings().wifiSsid().c_str(),
                       settings().wifiPass().c_str(),
                       settings().pcHost().c_str(),
                       settings().pcPort());
}

void enterListen() {
  gLink.disconnect();
  WiFi.disconnect(true);
  WiFi.mode(WIFI_OFF);
  gHeart.shutdown();
  gCamera.deinit();
  gAudio.setStreaming(true);  // mic -> on-device wake-word listener
  gState = DevState::Listen;
  gStateSinceMs = millis();
  Serial.println("[mode] listen (wi-fi off, wake word armed)");
}

void enterActive() {
  if (!linkConnection()) {
    enterListen();
    return;
  }
  gHeart.wake();
  gAudio.setStreaming(true);  // mic -> streamed up to Jarvis
  gState = DevState::Active;
  gStateSinceMs = millis();
  gLastCmdMs = millis();
  gLink.sendText("{\"type\":\"hello\",\"name\":\"arc-insight\",\"fw\":\"0.1\","
                 "\"wake\":%d}",
                 (int)wakeReason());
  gAudio.beep();
  Serial.println("[mode] active (streaming to jarvis)");
}

void enterDeepSleepNow() {
  gAudio.setStreaming(false);
  gAudio.beep();
  delay(120);
  gCamera.deinit();
  gHeart.shutdown();
  gLink.disconnect();
  WiFi.disconnect(true);
  WiFi.mode(WIFI_OFF);
  Serial.println("[mode] deep sleep (voice wake only)");
  enterDeepSleep(ARCI_SLEEP_GUARD_HOURS * 3600);
}

void doSnapshot() {
  bool wasActive = (gState == DevState::Active);
  if (!wasActive && !linkConnection()) {
    enterListen();
    return;
  }
  gSnapshotPending = true;
  gCamera.captureJpeg();
  gSnapshotPending = false;
  if (!wasActive) {
    uint32_t t0 = millis();
    while (millis() - t0 < 250) {
      gLink.loop();
      delay(2);
    }
    enterListen();
  }
}

void onPcm(const int16_t* pcm, size_t samples) {
  if (gState == DevState::Active) {
    gLink.sendBinary((uint8_t)BinaryOp::AudioPcm, (const uint8_t*)pcm,
                     samples * 2);
  } else {
    gKws.feed(pcm, samples);
  }
}

void onHr(int bpm, float confidence) {
  if (gState != DevState::Active) return;
  gLink.sendText("{\"type\":\"hr\",\"sample\":{\"bpm\":%d,"
                 "\"confidence\":%.2f,\"timestamp\":%lu}}",
                 bpm, confidence, (unsigned long)(millis() / 1000));
}

void onJpeg(const uint8_t* jpeg, size_t len) {
  if (gSnapshotPending) {
    gLink.sendBinary((uint8_t)BinaryOp::Snapshot, jpeg, len);
  } else {
    gLink.sendBinary((uint8_t)BinaryOp::ImageJpeg, jpeg, len);
  }
}

#if ARCI_ANCS_ENABLE
void sendNotify(const Ancs::Msg& m) {
  if (!gLink.connected()) return;
  gLink.sendText("{\"type\":\"notify\",\"sample\":{\"uid\":%lu,\"cat\":%d,"
                 "\"app\":\"%s\",\"source\":\"%s\",\"text\":\"%s\",\"ts\":%lu}}",
                 (unsigned long)m.uid, (int)m.category, m.app, m.source,
                 m.text, (unsigned long)(millis() / 1000));
}

void announceNotification(const Ancs::Msg& m) {
  Serial.printf("[ancs] announce cat=%d app=%s source=%s text=%.48s\n",
                (int)m.category, m.app, m.source, m.text);
  gAudio.beep();
  if (gState == DevState::Active) {
    sendNotify(m);
    return;
  }
  enterActive();
  sendNotify(m);
}

void onAncsNotify(const Ancs::Msg& m) {
  gLastAncsMsg = m;
  gAncsMsgPending = true;
}
#endif

void onBinary(uint8_t op, const uint8_t* data, size_t len) {
  switch ((BinaryOp)op) {
    case BinaryOp::AudioMp3:
      gAudio.feedMp3(data, len);
      gLastCmdMs = millis();
      break;
    case BinaryOp::FwChunk:
      if (gOtaActive && gOtaPartition) {
        if (esp_ota_write(gOtaHandle, data, len) == ESP_OK) {
          gOtaRecv += (uint32_t)len;
        }
        if (gOtaRecv >= gOtaSize) {
          finalizeOta();
        }
      }
      break;
    default:
      break;
  }
}

void parseWifiSet(const char* text);
void handleOtaBegin(const char* text);
void handleOtaEnd(const char* text);
void handleOtaAbort();

void onText(const char* text, size_t len) {
  (void)len;
  gLastCmdMs = millis();
  if (strstr(text, "ping")) {
    gLink.sendText("{\"type\":\"pong\"}");
  } else if (strstr(text, "capture")) {
    gCamera.captureJpeg();
  } else if (strstr(text, "microphone_on")) {
    gStreaming = true;
    gAudio.setStreaming(true);
  } else if (strstr(text, "microphone_off")) {
    gStreaming = false;
    gAudio.setStreaming(false);
  } else if (strstr(text, "go_sleep")) {
    enterDeepSleepNow();
  } else if (strstr(text, "ota_begin")) {
    handleOtaBegin(text);
  } else if (strstr(text, "ota_end")) {
    handleOtaEnd(text);
  } else if (strstr(text, "ota_abort")) {
    handleOtaAbort();
  } else if (strstr(text, "wifi_set")) {
    parseWifiSet(text);
  } else if (strstr(text, "get_status")) {
    gLink.sendText("{\"type\":\"status\",\"heap\":%lu,"
                   "\"rssi\":%d,\"streaming\":%d,\"mode\":%d}",
                   (unsigned long)ESP.getFreeHeap(), WiFi.RSSI(), gStreaming,
                   (int)gState);
  }
}

void parseWifiSet(const char* text) {
  const char* ssid = strstr(text, "ssid:");
  const char* pass = strstr(text, "pass:");
  const char* host = strstr(text, "host:");
  char s[64] = {0};
  char p[64] = {0};
  char h[96] = {0};
  if (ssid) sscanf(ssid, "ssid:%63[^|]", s);
  if (pass) sscanf(pass, "pass:%63[^|]", p);
  if (host) sscanf(host, "host:%95[^|]", h);
  if (s[0] && p[0]) settings().setWifi(s, p);
  if (h[0]) settings().setPcHost(h);
}

void handleOtaBegin(const char* text) {
  uint32_t size = 0;
  const char* key = strstr(text, "\"size\"");
  if (key) {
    const char* colon = strchr(key + 6, ':');
    if (colon) sscanf(colon + 1, "%u", &size);
  }
  if (!size) {
    const char* m = strstr(text, "size:");
    if (m) sscanf(m, "size:%u", &size);
  }
  if (!size) sscanf(text, "ota_begin %*[^:] : %u", &size);
  if (!size) return;
  const esp_partition_t* part =
      esp_partition_find_first(ESP_PARTITION_TYPE_APP,
                               ESP_PARTITION_SUBTYPE_APP_OTA_1, nullptr);
  if (!part) return;
  if (esp_ota_begin(part, size, &gOtaHandle) != ESP_OK) return;
  gOtaPartition = part;
  gOtaSize = size;
  gOtaRecv = 0;
  gOtaActive = true;
}

void handleOtaEnd(const char* text) {
  (void)text;
  if (!gOtaActive || !gOtaPartition) return;
  if (gOtaRecv < gOtaSize) {
    gLink.sendText("{\"type\":\"ota_event\",\"event\":\"device_error\","
                   "\"detail\":\"short transfer (%u of %u bytes)\"}",
                   (unsigned)gOtaRecv, (unsigned)gOtaSize);
    esp_ota_abort(gOtaHandle);
    gOtaActive = false;
    return;
  }
  finalizeOta();
}

void handleOtaAbort() {
  if (!gOtaActive || !gOtaPartition) return;
  esp_ota_abort(gOtaHandle);
  gOtaActive = false;
}

void handleGesture(Touch::Gesture g) {
  switch (g) {
    case Touch::Gesture::Tap:
      if (gState == DevState::Active) {
        Serial.println("[gesture] single tap -> listen");
        enterListen();
      }
      break;
    case Touch::Gesture::DoubleTap:
      Serial.println("[gesture] double tap -> snapshot");
      doSnapshot();
      break;
    case Touch::Gesture::Hold:
      Serial.println("[gesture] hold 5s -> deep sleep");
      enterDeepSleepNow();
      break;
    default:
      break;
  }
}

void handleSerial() {
  if (!Serial.available()) return;
  static String line;
  while (Serial.available()) {
    int c = Serial.read();
    if (c < 0) break;
    if (c == '\n') {
      line.trim();
      if (line == "cal_wake") {
        gKws.startCalibration();
      } else if (line == "state") {
        gKws.printState();
        Serial.printf("mode: %d (0=listen 1=active)\n", (int)gState);
      }
      line = "";
    } else {
      line += (char)c;
    }
  }
}

}  // namespace

void setup() {
  Serial.begin(115200);
  delay(120);
  Serial.println("ARC-INSIGHT v0.2");

#ifdef ARCI_SELFTEST
  runSelftest();
  Serial.println("[selftest] done");
  return;
#endif

  settings().begin();

  gLink.setHandlers(onBinary, onText);
  gAudio.onPcmReady(onPcm);
  gHeart.onData(onHr);
  gCamera.onData(onJpeg);

  gHeart.begin();
  gAudio.begin();
  gTouch.begin();
  gKws.begin();

#if ARCI_ANCS_ENABLE
  gAncs.setHandler(onAncsNotify);
  gAncs.begin();
#endif

  if (ARCI_KWS_ENABLE && !gKws.hasTemplate()) {
    Serial.println("[kws] no wake template yet: send \"cal_wake\" on serial");
  }

  enterListen();
}

void loop() {
#ifdef ARCI_SELFTEST
  delay(1000);
  return;
#endif

  handleSerial();

  Touch::Gesture g = gTouch.poll(millis());
  if (g != Touch::Gesture::None) handleGesture(g);

  gLink.loop();
  gAudio.poll();  // PCM goes to kws (listen) or the link (active)

#if ARCI_ANCS_ENABLE
  gAncs.poll();
  if (gAncsMsgPending) {
    gAncsMsgPending = false;
    announceNotification(gLastAncsMsg);
  }
#endif

  if (gState == DevState::Active) {
    if (gLink.connected()) {
      gHeart.poll(millis());
      if (millis() - gLastCmdMs > ARCI_IDLE_TIMEOUT_MS) {
        Serial.println("[idle] returning to listen");
        enterListen();
      }
    } else if (millis() - gStateSinceMs > ARCI_WS_TIMEOUT_MS) {
      enterListen();
    }
  } else {
    if (ARCI_KWS_ENABLE && gKws.detected()) {
      gKws.consumeDetected();
      enterActive();
    }
    if (millis() - gStateSinceMs >
        (uint32_t)ARCI_LISTEN_GUARD_HOURS * 3600000UL) {
      Serial.println("[guard] long idle, deep sleep");
      enterDeepSleepNow();
    }
  }
}

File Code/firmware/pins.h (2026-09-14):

#pragma once
#include <stdint.h>

namespace arcv {

#define ARCI_PIN_MIC_SCLK 11
#define ARCI_PIN_MIC_WS   10
#define ARCI_PIN_AMP_DIN  12
#define ARCI_PIN_MIC_DIN   9

// Amplifier is driven on the left slot; mic data lands on ARCI_MIC_RX_WORD.
#define ARCI_MIC_RX_WORD   1

#define ARCI_PIN_I2C_SDA   4
#define ARCI_PIN_I2C_SCL   5
#define ARCI_PIN_HR_INT    2

#define ARCI_PIN_WAKE     18

#define ARCI_PIN_TOUCH     1

#define ARCI_PIN_CAM_XCLK 13
#define ARCI_PIN_CAM_PCLK  8
#define ARCI_PIN_CAM_VSYNC 6
#define ARCI_PIN_CAM_HREF  7
#define ARCI_PIN_CAM_D7   39
#define ARCI_PIN_CAM_D6   40
#define ARCI_PIN_CAM_D5   41
#define ARCI_PIN_CAM_D4   42
#define ARCI_PIN_CAM_D3   38
#define ARCI_PIN_CAM_D2   45
#define ARCI_PIN_CAM_D1   21
#define ARCI_PIN_CAM_D0   14
#define ARCI_PIN_CAM_SIOD  4
#define ARCI_PIN_CAM_SIOC  5
#define ARCI_PIN_CAM_PWDN -1
#define ARCI_PIN_CAM_RESET -1

#define ARCI_WIRE_RATE_HZ  24000
#define ARCI_WIRE_BITS     (32)
#define ARCI_PCM_RATE_HZ   16000
#define ARCI_PCM_FRAME_MS  20
#define ARCI_PCM_FRAME_SAMPLES (ARCI_PCM_RATE_HZ * ARCI_PCM_FRAME_MS / 1000)

}  // namespace arcv

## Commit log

2026-09-10 Rename project to ARC-Insight; add firmware, PCB, and reference docs
    [arc-insight-board-B_Courtyard.gbr, arc-insight-board-B_Cu.gbl, arc-insight-board-B_Cu.gbr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]
2026-09-14 Add cap-touch firmware and TOUCH routing; refresh production outputs
    - Firmware: cap-touch reading on GPIO1 (touch.cpp/h), threshold 80, 900ms hold
    - PCB: route /TOUCH pad to ESP32; update schematic/project files
    - Regenerate gerbers (incl. /TOUCH net), drill files, positions.csv, BOM, gerbers.zip
    [arc-insight-board-B_Courtyard.gbr, arc-insight-board-B_Cu.gbl, arc-insight-board-B_Cu.gbr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]
2026-09-14 Refresh PCB production outputs; fix JLCPCB connector placement
    [arc-insight-board-B_Courtyard.gbr, arc-insight-board-B_Cu.gbl, arc-insight-board-B_Cu.gbr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]
2026-09-14 Add How to use instructions; ignore KiCad lock files
2026-09-15 Add on-device wake word + button gestures (Option A)
    Glasses now rest with Wi-Fi off, listening for the word 'jarvis'
    via a self-contained template-matching spotter (no model). Only after
    detection do they connect and stream to Jarvis.
    - kws.h/kws.cpp: 256-pt FFT, 12 mel bands + energy, VAD, 16-slice
    template matched by cosine similarity, stored in NVS. Calibrate with
    'cal_wake' over serial (3 utterances). Threshold 0.68.
    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
2026-09-16 Rewrite schematic to label-based net connectivity matching PCB
    [arc-insight-board.kicad_sch]
2026-09-22 Add ANCS notification broadcasting from iPhone to the glasses host
    Glasses firmware now advertises the ANCS service as 'ARC-INSIGHT',
    pairs/bonds with the iPhone, and forwards notification metadata as
    notify messages over the WebSocket. The host dedupes by UID, formats
    announcements (category label + sender + text) through the existing
    TTS path, and respects notify.enabled/announce/suppress_categories/
    max_text_chars. NimBLE-Arduino 2.4.0 added; sendText buffer bumped.
2026-10-03 Rewrite schematic with wired layout, CC pulldowns, grounded shield, drop L1
    [arc-insight-board.kicad_sch]
2026-10-03 Update PCB: add R8/R9 CC pulldowns, ground USB-C shield
    [arc-insight-board.kicad_pcb, arc-insight-board.kicad_sch]
2026-10-03 Update PCB for rewired schematic and regenerate fab outputs
    [arc-insight-board-B_Courtyard.gbr, arc-insight-board-B_Cu.gbl, arc-insight-board-B_Cu.gbr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]
2026-10-08 Edited files
    [arc-insight-board-B_Courtyard.gbr, arc-insight-board-B_Cu.gbl, arc-insight-board-B_Cu.gbr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]
2026-10-08 Remove stale positions.csv, add LCSC part for R8/R9 CC pulldowns
    [bom.csv, positions.csv]
2026-10-09 Update PCB and refresh fab bundle, CPL and BOM
    [arc-insight-board-B_Courtyard.gbr, arc-insight-board-B_Cu.gbl, arc-insight-board-B_Cu.gbr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]
2026-10-10 Update PCB and refresh fab bundle
2026-10-15 Fix BOM LCSC numbers and keep full JLC CPL
2026-10-21 Fix U1 (ESP32-S3FN8/C2913196) and Y1 (2520 4-pin crystal/C37635359); update BOMs, gerbers, positions
2026-10-23 Fix CPL coordinate origin (restore negative Y) and shift USB-C (J1) left 0.75mm
2026-10-23 Shift J1 left 0.2mm and J8 down 0.8mm in CPL
2026-10-23 CPL: J1 left 0.1mm; U4/U5 rotate 180; U6 rotate 90
